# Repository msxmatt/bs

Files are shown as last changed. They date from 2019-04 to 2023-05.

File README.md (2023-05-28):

[][cc-by-sa] 

# bs
Bluetooth Sorry (BS)

# Hardware

## Specification

Please see the [specification](https://docs.google.com/document/d/1cNCA_kc3GKC5SSItixQ384-7OVhhF-bT8k4SdFTyF7Y/edit?usp=sharing) on Google Docs for more information.

# Firmware

# Licensing

## Hardware

Bluetooth Sorry (BS) hardware is licensed under a
[Creative Commons Attribution-ShareAlike 4.0 International License][cc-by-sa].  For more information, please see the LICENSE file included in this repo.

[][cc-by-sa]<br><br>
[OSHWA][open-hardware-url]

[cc-by-sa]: http://creativecommons.org/licenses/by-sa/4.0/
[cc-by-sa-image]: https://licensebuttons.net/l/by-sa/4.0/88x31.png
[cc-by-sa-shield]: https://img.shields.io/badge/License-CC%20BY--SA%204.0-lightgrey.svg
[open-hardware-url]: https://www.oshwa.org/
[open-hardware-image]: https://i0.wp.com/www.oshwa.org/wp-content/uploads/2014/03/oshw-logo-100-px.png

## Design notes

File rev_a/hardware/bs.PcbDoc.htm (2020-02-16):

Reporting Options

# File in Previous Format

Date | : | 2/16/2020
Time | : | 3:05:59 PM
Filename | : | C:\git\msx\bs\PCB\bs.PcbDoc

Version | Warning

This file was generated by an earlier version of the software

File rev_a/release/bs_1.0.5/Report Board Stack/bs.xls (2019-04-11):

Board Stack Report
Stack Up |  | Layer Stack
Layer | Board Layer Stack | Name | Material | Thickness | Constant
1 |  | Top Paste
2 |  | Top Overlay
3 |  | Top Solder | SM-001 | 1.00mil | 4
4 |  | Top Layer | Copper | 1.38mil
5 |  | Dielectric 1 | PP-021 | 7.10mil | 4.7
6 |  | Int1 (GND) | Copper | 1.38mil
7 |  | Dielectric 2 | CircuitHub-4L | 11.81mil | 4.6
8 |  | Int2 (PWR) | Copper | 1.38mil
9 |  | Dielectric 3 | PP-021 | 7.10mil | 4.7
10 |  | Bottom Layer | Copper | 1.38mil
11 |  | Bottom Solder | SM-001 | 1.00mil | 4
12 |  | Bottom Overlay
13 |  | Bottom Paste
 | Height : 33.52mil

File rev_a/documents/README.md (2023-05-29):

# Bluetooth Sorry (BS) Rev A Documents

All documentation has been converted to Google Docs and Lucidchart to make it more accessible for folks.  Please see the links below to access the documentation for this project:

### [Architecture Drawings](https://lucid.app/lucidchart/962b5e3b-6578-4df2-a3c6-de9c28ae3cac/edit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)
### [Battery Calculator](https://docs.google.com/spreadsheets/d/11GxPMdcu_zIT5CegySkwF_FRTmmZH-5FmrIwhb1siNY/edit?usp=sharing)
### [Layout Rules and Guidelines](https://docs.google.com/document/d/1B4_djOARfETP27NwB1YwL5EQ4x5ZWdFKNO-U1eI23VM/edit?usp=sharing)
### [Bring-Up Testing Overview](https://docs.google.com/spreadsheets/d/1GfkkhbxSuywVHKYCwezCMSKbZUOoyDMGrd5bFZc0WWg/edit?usp=sharing)
### [Rev B Fixes and Ideas](https://docs.google.com/document/d/1f-UJx_TAneLSBL5eTnIvvRchRN2FdRKdbjY0LI8uTsM/edit?usp=drive_link)

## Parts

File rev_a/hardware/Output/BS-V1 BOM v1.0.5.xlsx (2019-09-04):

BOM: |  |  | BS-V1
Assembly Part Number: |  |  | BS-V1-ASSY
Revision: |  |  | 1.0.5
Customer / Company Name: |  |  | MSX Consulting, LLC
Item # | Quantity | Manufacturer | Manufacturer Part Number | Level | Fitted | Designator | Supplier 1 | Supplier Part Number 1 | Comment | Footprint | Description
1 | 3 | Samsung | CL05A106MP5NUNC | 1 | Fitted | C1, C10, C12 | Digi-Key | 1276-1450-1-ND | 10uF | C0402 | CAP CER 10UF 10V X5R 0402
2 | 3 | Samsung | CL05A475MO5NUNC | 1 | Fitted | C2, C3, C9 | Digi-Key | 1276-6836-1-ND | 4.7uF | C0402 | CAP CER 4.7UF 16V X5R 0402
3 | 2 | Taiyo Yuden | TMK105BJ105MV-F | 1 | Fitted | C4, C6 | Digi-Key | 587-3245-1-ND | 1uF | C0402 | CAP CER 1UF 25V X5R 0402
4 | 4 | Murata | GRM033R61C104ME84D | 1 | Fitted | C5, C7, C8, C14 | Digi-Key | 490-9986-1-ND | 0.1uF | C0201 | CAP CER 0.1UF 16V X5R 0201
5 | 1 | Murata | GRM155R71E103KA01D | 1 | Fitted | C11 | Digi-Key | 490-1312-1-ND | 10000pF | C0402 | CAP CER 10000PF 25V X7R 0402
6 | 1 | Murata | GRM155R71C153KA01J | 1 | Fitted | C13 | Digi-Key | 490-6329-1-ND | 0.015uF | C0402 | CAP CER 0.015UF 16V X7R 0402
7 | 2 | STMicroelectronics | ESDAXLC6-1BU2 | 1 | Fitted | D1, D7 | Digi-Key | 497-13414-1-ND | ESDAXLC6-1BU2 | ONS_0201 | TVS DIODE 3V 17V ST0201
8 | 2 | Dialight | 598-8070-107F | 1 | Fitted | D2, D6 | Digi-Key | 350-2035-1-ND | 5988070107F | LED0603 | LED GREEN CLEAR 0603 SMD
9 | 1 | MCC | 1N4148X-TP | 1 | Fitted | D3 | Digi-Key | 1N4148XTPMSCT-ND | 1N4148X-TP | MCC_SOD523 | DIODE GEN PURP 75V 150MA SOD523
10 | 1 | NXP Semiconductors | PMEG2020EPK,315 | 1 | Fitted | D4 | Digi-Key | 1727-1338-1-ND | PMEG2020EPK | NXP_DFN1608D-2 | DIODE SCHOTTKY 20V 2A 2DFN
11 | 1 | Dialight | 598-8091-107F | 1 | Fitted | D5 | Digi-Key | 350-2037-1-ND | 5988091107F | LED0603 | LED BLUE CLEAR 0603 SMD
12 | 1 | STMicroelectronics | ESDA7P60-1U1M | 1 | Fitted | D8 | Digi-Key | 497-16253-1-ND | ESDA7P60-1U1M | STM_1610 | TVS DIODE 5V 11.6V 1610
13 | 1 | Amphenol FCI | 10132328-10011LF | 1 | Fitted | J1 | Digi-Key | 609-5380-1-ND | 10132328-10011LF | AMP_USBC_VT | CONN RCPT USB3.1 TYPEC 24POS SMD
14 | 1 | Tag Connect | TC2030-IDC-NL | 1 | Fitted | J2 | N/A | N/A | TC2030-IDC-NL | TAG_6P | TAG CONNECT 6PIN SWD
15 | 1 | JST | B2B-ZR(LF)(SN) | 1 | Fitted | J3 | Digi-Key | 455-1657-ND | B2B-ZR(LF)(SN) | JST_ZH_2P_PTH_VT | CONN HEADER ZH TOP 2POS 1.5MM
16 | 1 | Sullins | GRPB022VWVN-RC | 1 | Fitted | J4 | Digi-Key | S9015E-02-ND | GRPB022VWVN-RC | HDR10_2X2_0.05IN | CONN HEADER VERT 4POS 1.27MM
17 | 1 | Murata | BLM15PX601SN1D | 1 | Fitted | L1 | Digi-Key | 490-9657-1-ND | BLM15PX601SN1D | L0402 | FERRITE BEAD 600 OHM 0402 1LN
18 | 1 | Diodes | DMP21D0UFB4-7B | 1 | Fitted | Q1 | Digi-Key | DMP21D0UFB4-7BDICT-ND | DMP21D0UFB4-7B | DIO_X2-DFN1006-3 | MOSFET P-CH 20V 770MA 3DFN
19 | 2 | Yageo | RC0402FR-075K1L | 1 | Fitted | R1, R2 | Digi-Key | 311-5.10KLRCT-ND | 5.1k | R0402 | RES SMD 5.1K OHM 1% 1/16W 0402
20 | 2 | Yageo | RC0402FR-0747RL | 1 | Fitted | R3, R15 | Digi-Key | 311-47.0LRCT-ND | 47R | R0402 | RES SMD 47 OHM 1% 1/16W 0402
21 | 2 | Yageo Phycomp | RC0402FR-0710KL | 1 | Fitted | R4, R11 | Digi-Key | 311-10.0KLRCT-ND | 10k | R0402 | RES SMD 10K OHM 1% 1/16W 0402
22 | 3 | Yageo | RC0402FR-071KL | 1 | Fitted | R5, R9, R16 | Digi-Key | 311-1.00KLRCT-ND | 1k | R0402 | RES SMD 1K OHM 1% 1/16W 0402
23 | 1 | Yageo | RC0402FR-072KL | 1 | Fitted | R6 | Digi-Key | 311-2KLRCT-ND | 2k | R0402 | RES SMD 2K OHM 1% 1/16W 0402
24 | 1 | Panasonic | ERJ-2RKF8063X | 1 | Fitted | R7 | Digi-Key | P806KLCT-ND | 806k | R0402 | RES SMD 806K OHM 1% 1/10W 0402
25 | 1 | Samsung | RC1005F205CS | 1 | Fitted | R8 | Digi-Key | 1276-4293-1-ND | 2M | R0402 | RES SMD 2M OHM 1% 1/16W 0402
26 | 1 | Yageo | RC0402FR-070RL | 1 | Fitted | R12 | Digi-Key | 311-0.0LRCT-ND | 0R | R0402 | RES SMD 0 OHM JUMPER 1/16W 0402
27 | 1 | Yageo | RC0402FR-07100KL | 1 | Fitted | R13 | Digi-Key | 311-100KLRCT-ND | 100k | R0402 | RES SMD 100K OHM 1% 1/16W 0402
28 | 1 | Panasonic | ERJ-2RKF3571X | 1 | Fitted | R14 | Digi-Key | P3.57KLCT-ND | 3.57k | R0402 | RES SMD 3.57K OHM 1% 1/10W 0402
29 | 1 | Panasonic | ERJ-2RKF1151X | 1 | Fitted | R17 | Digi-Key | P1.15KLCT-ND | 1.15k | R0402 | RES SMD 1.15K OHM 1% 1/10W 0402
30 | 1 | TE Connectivity Alcoswitch | FSMIJM61AB04 | 1 | Fitted | SW1 | Digikey | 450-2207-1-ND | FSMIJM61AB04 | TE_FSMIJM61AB04 | SWITCH TACTILE SPST-NO 50MA 12V
31 | 1 | Panasonic | EXC-14CS350H | 1 | Fitted | U1 | Digi-Key | P19421CT-ND | EXC-14CS350H | PAN_EXC14CS | CMC 100MA 2LN 35 OHM SMD ESD
32 | 1 | Seeed Studio | 317030213 | 1 | Fitted | U2 | Digi-Key | 1597-1434-ND | MDBT42Q | RAY_MDBT42Q | MDBT42Q NRF52832 BASED BLE MODUL
33 | 1 | Microchip | MCP73831T-2ATI/OT | 1 | Fitted | U3 | Digi-Key | MCP73831T-2ATI/OTCT-ND | MCP73831T-2ATI/OT | MCP_SOT23-5 | IC CONTROLLR LI-ION 4.2V SOT23-5
34 | 1 | Silicon Labs | CP2104-F03-GMR | 1 | Fitted | U4 | Digi-Key | 336-4146-1-ND | CP2104-F03-GMR | SIL_QFN-24 | IC SGL USB-TO-UART BRIDGE 24QFN
35 | 1 | Texas Instruments | TPS7A9001DSKR | 1 | Fitted | U5 | Digi-Key | 296-48316-1-ND | TPS7A9001DSKR | TI_DSK | ULTRA LOW NOISE 0.5A LDO WITH P
END OF BOM

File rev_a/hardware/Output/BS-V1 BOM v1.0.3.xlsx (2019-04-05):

BOM: BS-V1
Assembly Part Number/Revision: BS-V1-ASSY v1.0.3
Customer / Company Name: MSX Consulting, LLC.
Item # | Qty | Manfacturer | Manufacturer Part # | Level | Do Not Install | Reference designators | Vendor | Vendor Part Number | Value | Size / Footprint | Description
1 | 3 | Samsung | CL05A106MP5NUNC | 1 |  | C1, C10, C12 | Digi-Key | 1276-1450-1-ND | 10uF | C0402 | CAP CER 10UF 10V X5R 0402
2 | 3 | Samsung | CL05A475MO5NUNC | 1 |  | C2, C3, C9 | Digi-Key | 1276-6836-1-ND | 4.7uF | C0402 | CAP CER 4.7UF 16V X5R 0402
3 | 2 | Taiyo Yuden | TMK105BJ105MV-F | 1 |  | C4, C6 | Digi-Key | 587-3245-1-ND | 1uF | C0402 | CAP CER 1UF 25V X5R 0402
4 | 3 | Taiyo Yuden | TMK105B7104KVHF | 1 |  | C5, C7, C8 | Digi-Key | 587-3773-1-ND | 0.1uF | C0402 | CAP CER 0.1UF 25V X7R 0402
5 | 1 | Murata | GRM155R71E103KA01D | 1 |  | C11 | Digi-Key | 490-1312-1-ND | 10000pF | C0402 | CAP CER 10000PF 25V X7R 0402
6 | 1 | Murata | GRM155R71C153KA01J | 1 |  | C13 | Digi-Key | 490-6329-1-ND | 0.015uF | C0402 | CAP CER 0.015UF 16V X7R 0402
7 | 1 | STMicroelectronics | ESDAXLC6-1BU2 | 1 |  | D1 | Digi-Key | 497-13414-1-ND | ESDAXLC6-1BU2 | ONS_0201 | TVS DIODE 3V 17V ST0201
8 | 2 | Dialight | 598-8070-107F | 1 |  | D2, D6 | Digi-Key | 350-2035-1-ND | 5988070107F | LED0603 | LED GREEN CLEAR 0603 SMD
9 | 1 | ON Semiconductor | MMBD914LT1G | 1 |  | D3 | Digi-Key | MMBD914LT1GOSCT-ND | MMBD914LT1G | ONS_SOT23 | DIODE GEN PURP 100V 200MA SOT23
10 | 1 | NXP Semiconductors | PMEG2020EPK,315 | 1 |  | D4 | Digi-Key | 1727-1338-1-ND | PMEG2020EPK | NXP_DFN1608D-2 | DIODE SCHOTTKY 20V 2A 2DFN
11 | 1 | Dialight | 598-8091-107F | 1 |  | D5 | Digi-Key | 350-2037-1-ND | 5988091107F | LED0603 | LED BLUE CLEAR 0603 SMD
12 | 1 | Amphenol FCI | 10132328-10011LF | 1 |  | J1 | Digi-Key | 609-5380-1-ND | 10132328-10011LF | AMP_USBC_VT | CONN RCPT USB3.1 TYPEC 24POS SMD
13 | 1 | Tag-Connect | TC2030-IDC-NL | 1 | DNI | J2 | N/A | N/A | TC2030-IDC-NL | TAG_6P | TAG CONNECT 6PIN SWD
14 | 1 | JST | B2B-ZR(LF)(SN) | 1 |  | J3 | Digi-Key | 455-1657-ND | B2B-ZR(LF)(SN) | JST_ZH_2P_PTH_VT | CONN HEADER ZH TOP 2POS 1.5MM
15 | 1 | Harwin | M22-5320546 | 1 |  | J4 | Digi-Key | 952-3345-ND | M22-5320546 | HDR10_2X5_2MM | CONN HEADER SMD 10POS 2MM
16 | 1 | Diodes | DMP21D0UFB4-7B | 1 |  | Q1 | Digi-Key | DMP21D0UFB4-7BDICT-ND | DMP21D0UFB4-7B | DIO_X2-DFN1006-3 | MOSFET P-CH 20V 770MA 3DFN
17 | 2 | Yageo | RC0402FR-075K1L | 1 |  | R1, R2 | Digi-Key | 311-5.10KLRCT-ND | 5.1k | R0402 | RES SMD 5.1K OHM 1% 1/16W 0402
18 | 2 | Yageo | RC0402FR-0747RL | 1 |  | R3, R15 | Digi-Key | 311-47.0LRCT-ND | 47R | R0402 | RES SMD 47 OHM 1% 1/16W 0402
19 | 2 | Yageo | RC0402FR-0710KL | 1 |  | R4, R11 | Digi-Key | 311-10.0KLRCT-ND | 10k | R0402 | RES SMD 10K OHM 1% 1/16W 0402
20 | 3 | Yageo | RC0402FR-071KL | 1 |  | R5, R9, R16 | Digi-Key | 311-1.00KLRCT-ND | 1k | R0402 | RES SMD 1K OHM 1% 1/16W 0402
21 | 1 | Yageo | RC0402FR-072KL | 1 |  | R6 | Digi-Key | 311-2KLRCT-ND | 2k | R0402 | RES SMD 2K OHM 1% 1/16W 0402
22 | 1 | Panasonic | ERJ-2RKF8063X | 1 |  | R7 | Digi-Key | P806KLCT-ND | 806k | R0402 | RES SMD 806K OHM 1% 1/10W 0402
23 | 1 | Samsung | RC1005F205CS | 1 |  | R8 | Digi-Key | 1276-4293-1-ND | 2M | R0402 | RES SMD 2M OHM 1% 1/16W 0402
24 | 1 | Yageo | RC0402FR-074K7L | 1 |  | R10 | Digi-Key | 311-4.7KLRCT-ND | 4.7k | R0402 | RES SMD 4.7K OHM 1% 1/16W 0402
25 | 1 | Yageo | RC0402FR-070RL | 1 |  | R12 | Digi-Key | 311-0.0LRCT-ND | 0R | R0402 | RES SMD 0 OHM JUMPER 1/16W 0402
26 | 1 | Yageo | RC0402FR-07100KL | 1 |  | R13 | Digi-Key | 311-100KLRCT-ND | 100k | R0402 | RES SMD 100K OHM 1% 1/16W 0402
27 | 1 | Panasonic | ERJ-2RKF3571X | 1 |  | R14 | Digi-Key | P3.57KLCT-ND | 3.57k | R0402 | RES SMD 3.57K OHM 1% 1/10W 0402
28 | 1 | Panasonic | ERJ-2RKF1151X | 1 |  | R17 | Digi-Key | P1.15KLCT-ND | 1.15k | R0402 | RES SMD 1.15K OHM 1% 1/10W 0402
29 | 1 | TE Connectivity Alcoswitch | FSMIJM61AB04 | 1 |  | SW1 | Digi-Key | 450-2207-1-ND | FSMIJM61AB04 | TE_FSMIJM61AB04 | SWITCH TACTILE SPST-NO 50MA 12V
30 | 1 | ITT C&K | PTS645SM43SMTR92LFS | 1 |  | SW2 | Digi-Key | CKN9112CT-ND | PTS645SM43SMTR92LFS | CK_PTS645 | SWITCH TACTILE SPST-NO 0.05A 12V
31 | 1 | STMicroelectronics | ECMF02-4CMX8 | 1 |  | U1 | Digi-Key | 497-13420-1-ND | ECMF02-4CMX8 | STM_UQFN-8L | COMMON MODE CHOKE 2LN SMD ESD
32 | 1 | Seeed Studio | 317030213 | 1 |  | U2 | Digi-Key | 1597-1434-ND | MDBT42Q | RAY_MDBT42Q | MDBT42Q NRF52832 BASED BLE MODUL
33 | 1 | Microchip | MCP73831T-2ATI/OT | 1 |  | U3 | Digi-Key | MCP73831T-2ATI/OTCT-ND | MCP73831T-2ATI/OT | MCP_SOT23-5 | IC CONTROLLR LI-ION 4.2V SOT23-5
34 | 1 | Silicon Labs | CP2104-F03-GMR | 1 |  | U4 | Digi-Key | 336-4146-1-ND | CP2104-F03-GMR | SIL_QFN-24 | IC SGL USB-TO-UART BRIDGE 24QFN
35 | 1 | Texas Instruments | TPS7A9001DSKR | 1 |  | U5 | Digi-Key | 296-48316-1-ND | TPS7A9001DSKR | TI_DSK | ULTRA LOW NOISE 0.5A LDO WITH P
END OF BOM

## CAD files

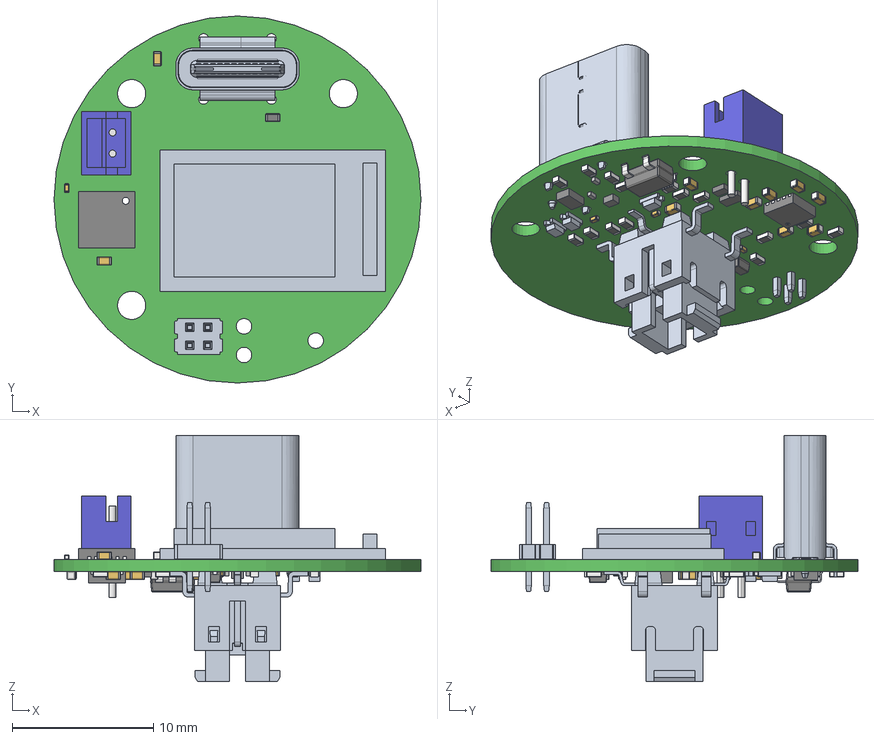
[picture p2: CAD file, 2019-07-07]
rev_a/mechanical/MCO Mockup v1.1.step
26.0 x 26.0 x 17.5 mm
Open_CASCADE_STEP_translator_6.8_1.1.1 x 7
Open_CASCADE_STEP_translator_6.8_1.1.2 x 5
Open_CASCADE_STEP_translator_6.8_1.2.1 x 38
bigPin x 5
Open_CASCADE_STEP_translator_6.8_5.1.1 x 10
Open_CASCADE_STEP_translator_6.8_5.1.2 x 10
Open_CASCADE_STEP_translator_6.8_5.2.1 x 10
Extruded x 3
c-2213819-1-a-3d
Open_CASCADE_STEP_translator_6.8_2.1
Open_CASCADE_STEP_translator_6.8_2.2.1
Thermal_Shape x 2
Open_CASCADE_STEP_translator_6.8_2.4.1 x 10
Open_CASCADE_STEP_translator_6.8_2.4.2 x 10
Open_CASCADE_STEP_translator_6.8_1.1
Open_CASCADE_STEP_translator_6.8_1.4.1 x 24
Leader x 5
mdbt42q
Mid_Body x 16
Mark x 16
smallPine x 2
_____B022VWVN-RC
B2B-ZR
10132328-10011LF
0603_single x 3
lead x 2

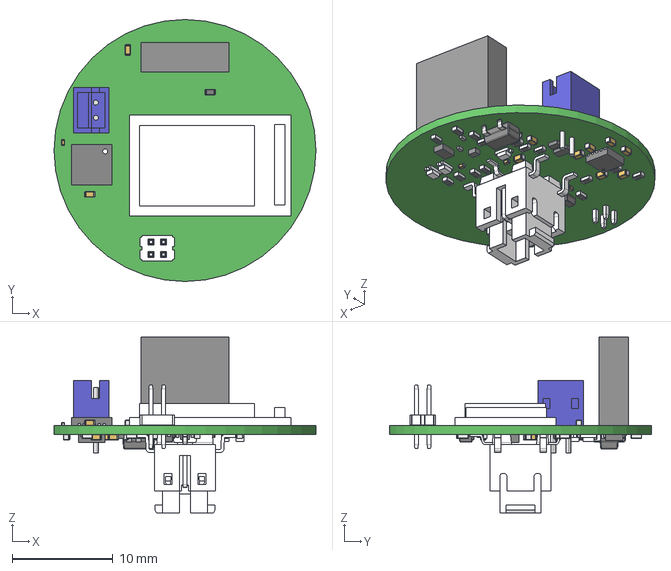
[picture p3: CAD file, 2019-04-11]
rev_a/release/bs_1.0.5/ExportSTEP/bs.step
26.0 x 26.0 x 17.5 mm

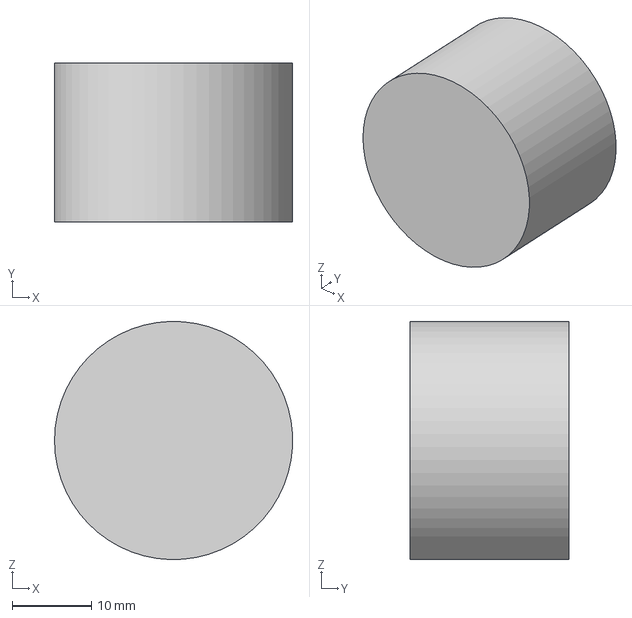
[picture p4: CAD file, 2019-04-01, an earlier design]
rev_a/mechanical/MCO Mockup v1.step
30.0 x 20.0 x 30.0 mm

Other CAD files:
rev_a/mechanical/MCO.dwg

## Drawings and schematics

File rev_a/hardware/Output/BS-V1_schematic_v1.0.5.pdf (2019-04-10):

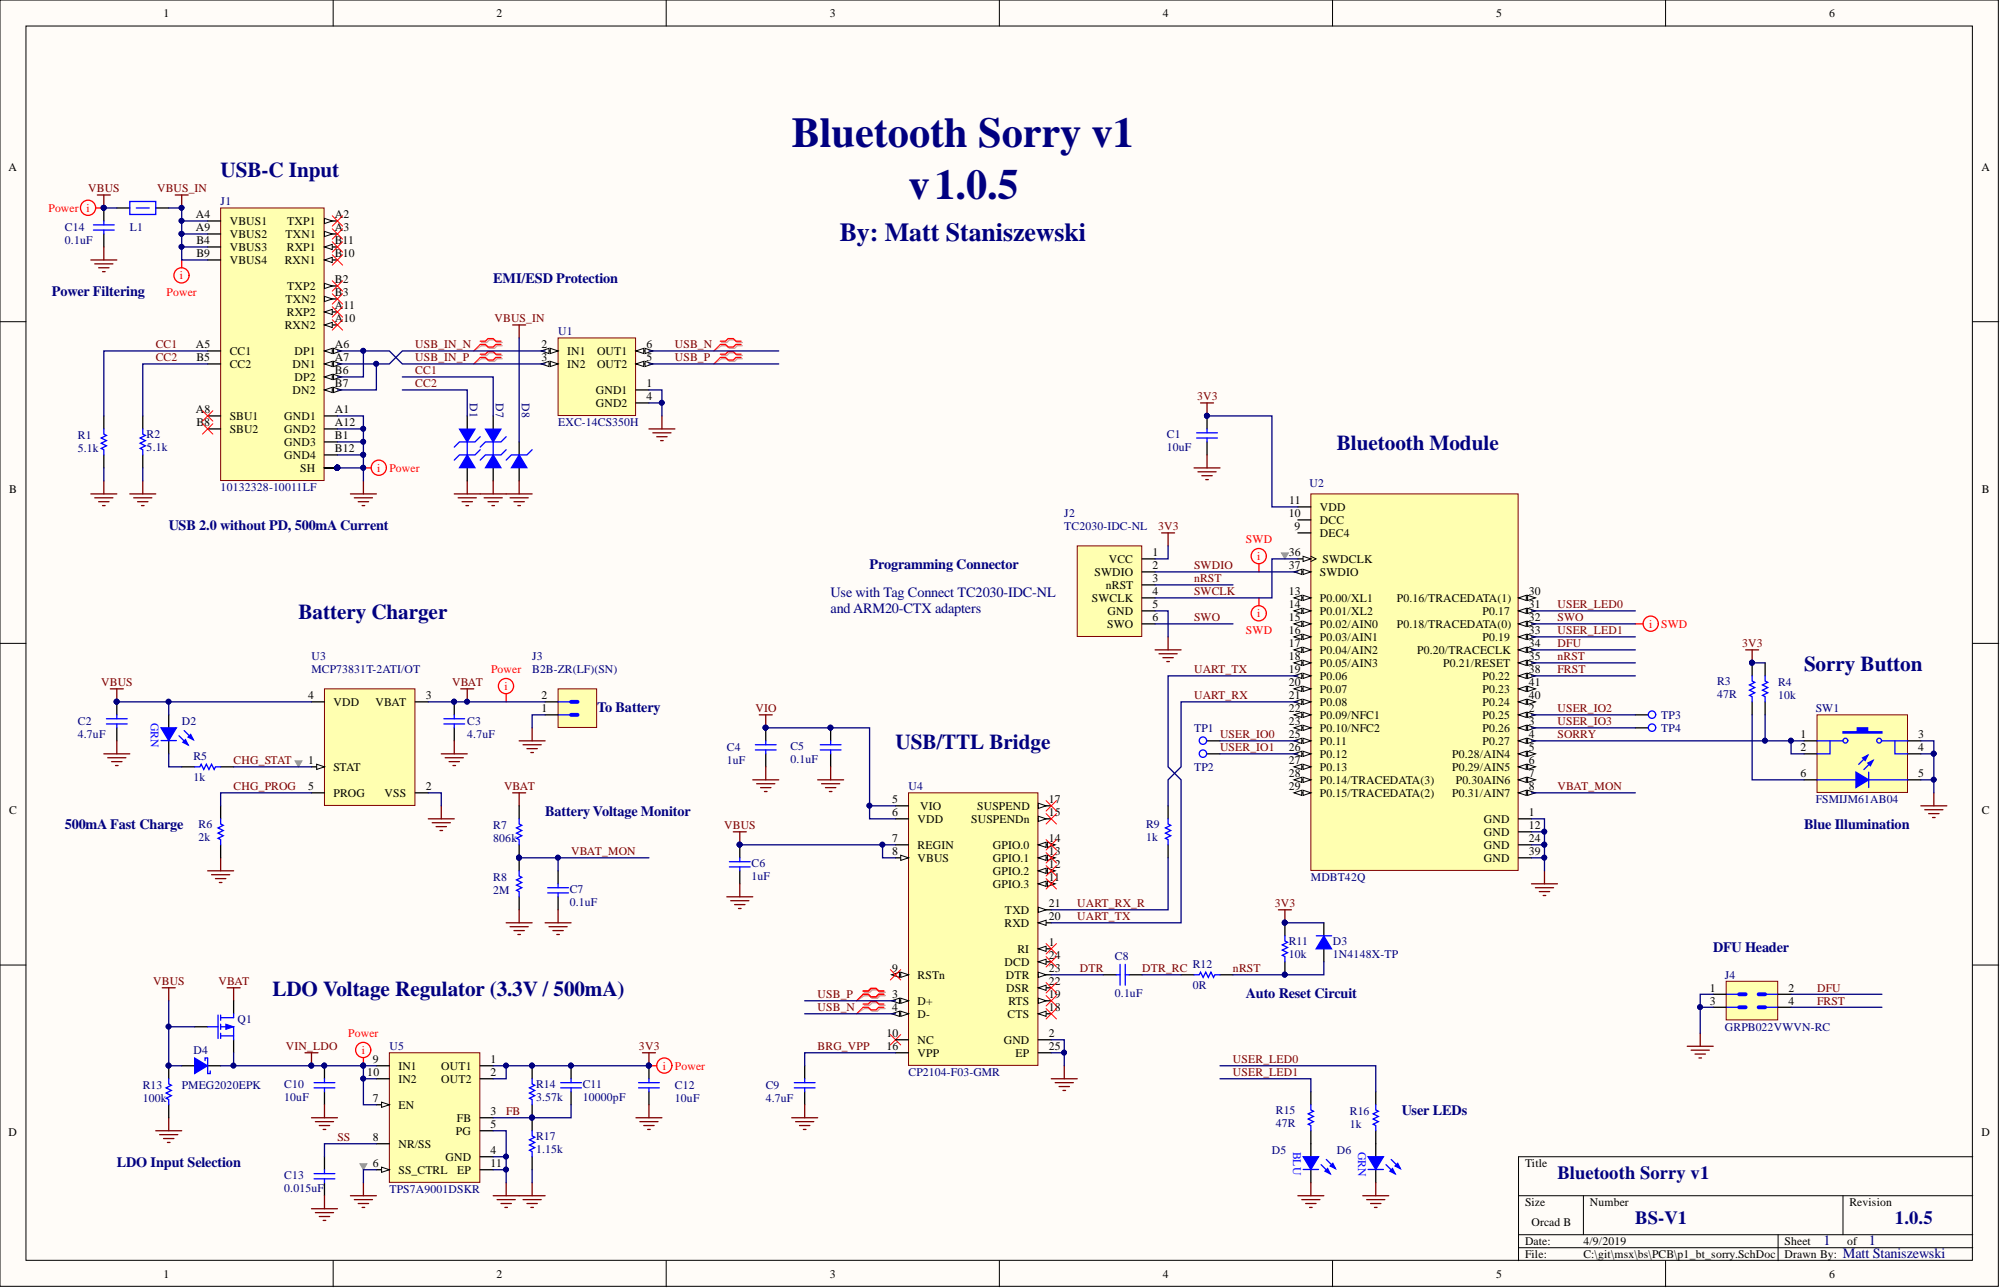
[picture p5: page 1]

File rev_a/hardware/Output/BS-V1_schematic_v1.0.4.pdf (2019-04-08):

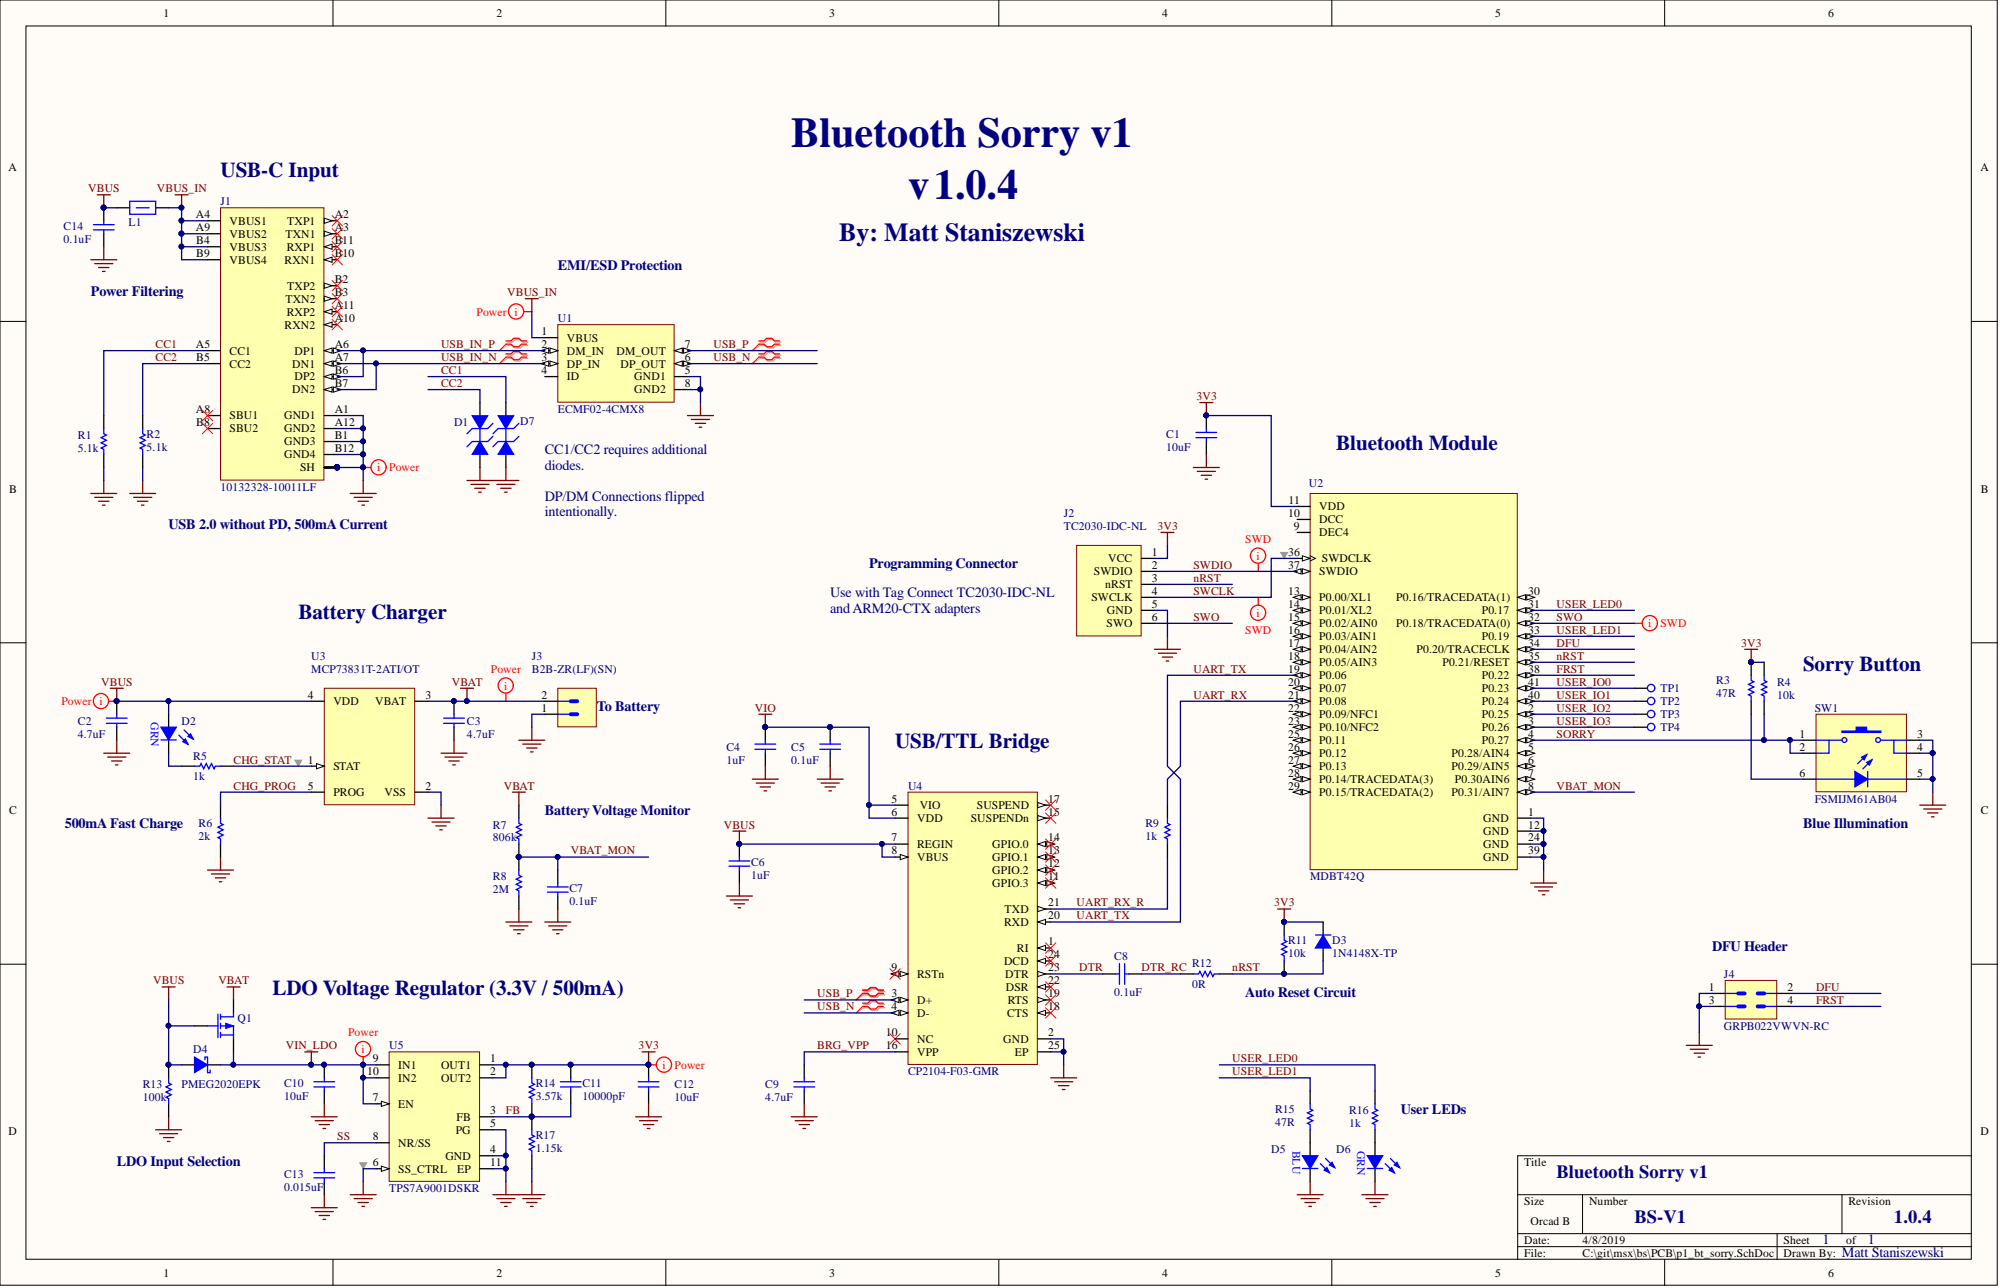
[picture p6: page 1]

CC2 | | CC2 B5 | A 7 | USB_IN _ N 3

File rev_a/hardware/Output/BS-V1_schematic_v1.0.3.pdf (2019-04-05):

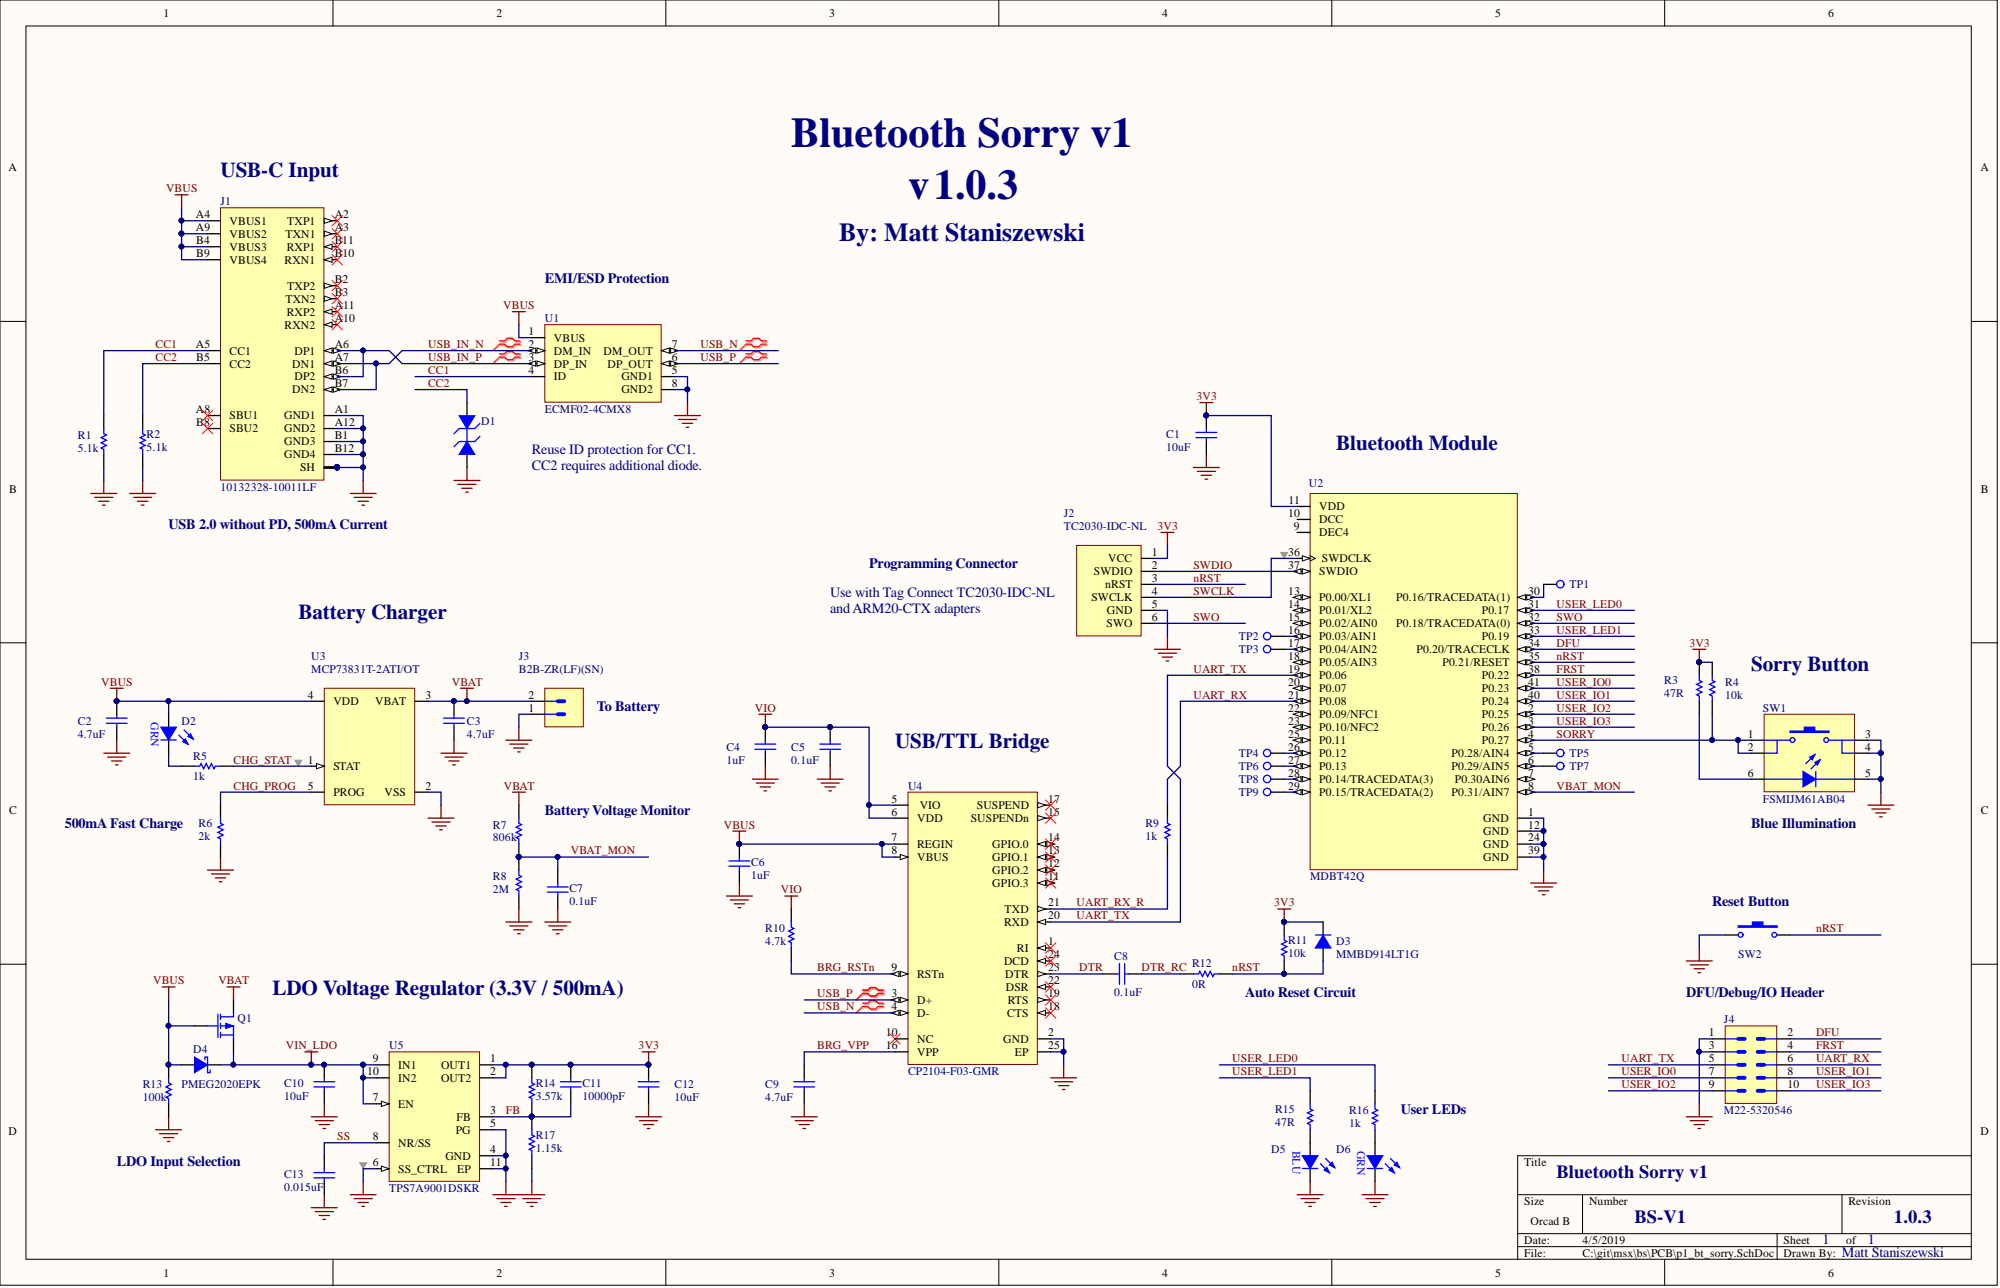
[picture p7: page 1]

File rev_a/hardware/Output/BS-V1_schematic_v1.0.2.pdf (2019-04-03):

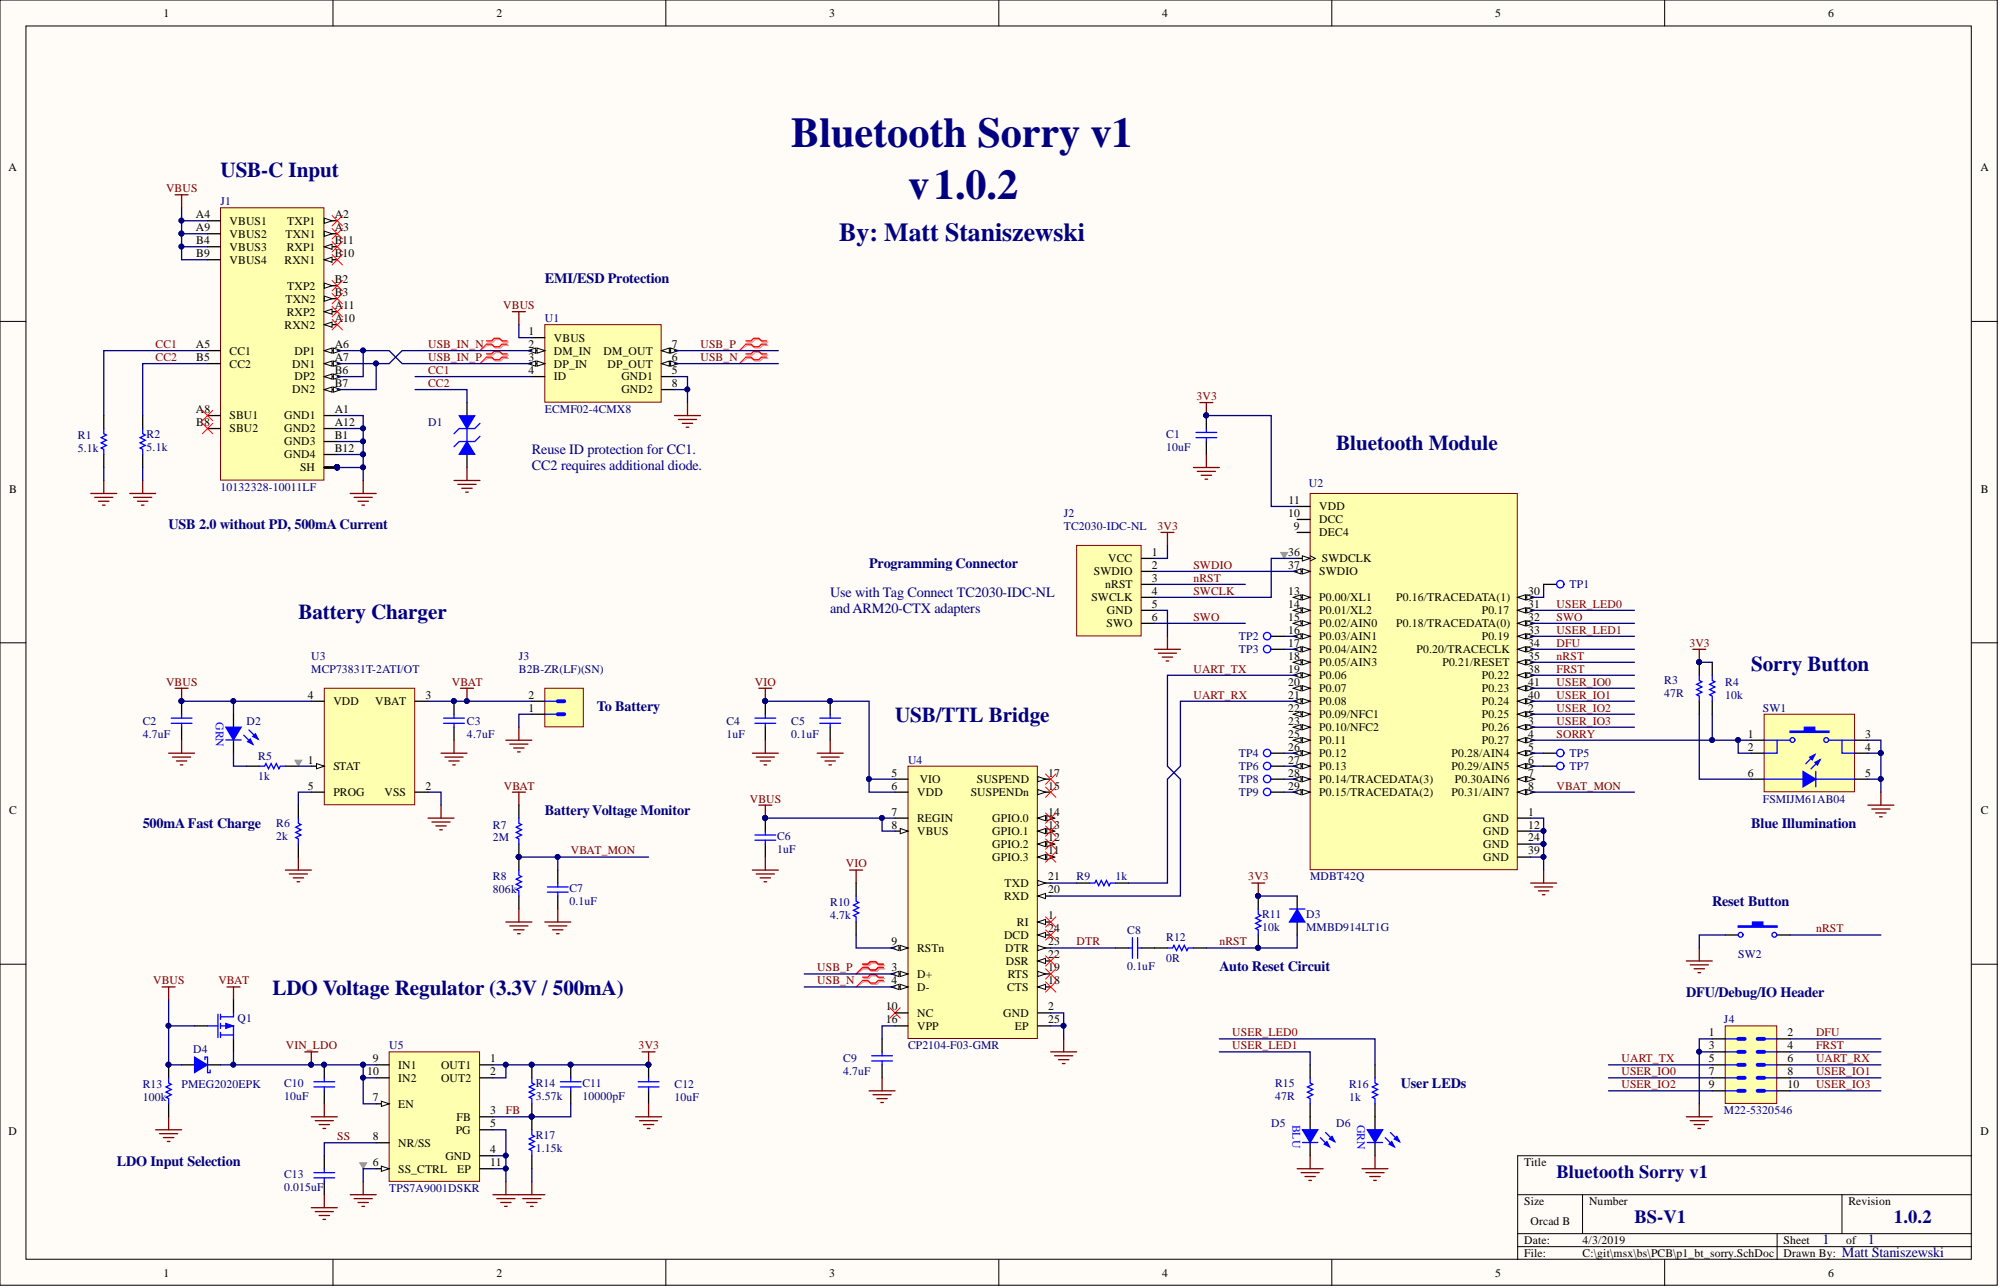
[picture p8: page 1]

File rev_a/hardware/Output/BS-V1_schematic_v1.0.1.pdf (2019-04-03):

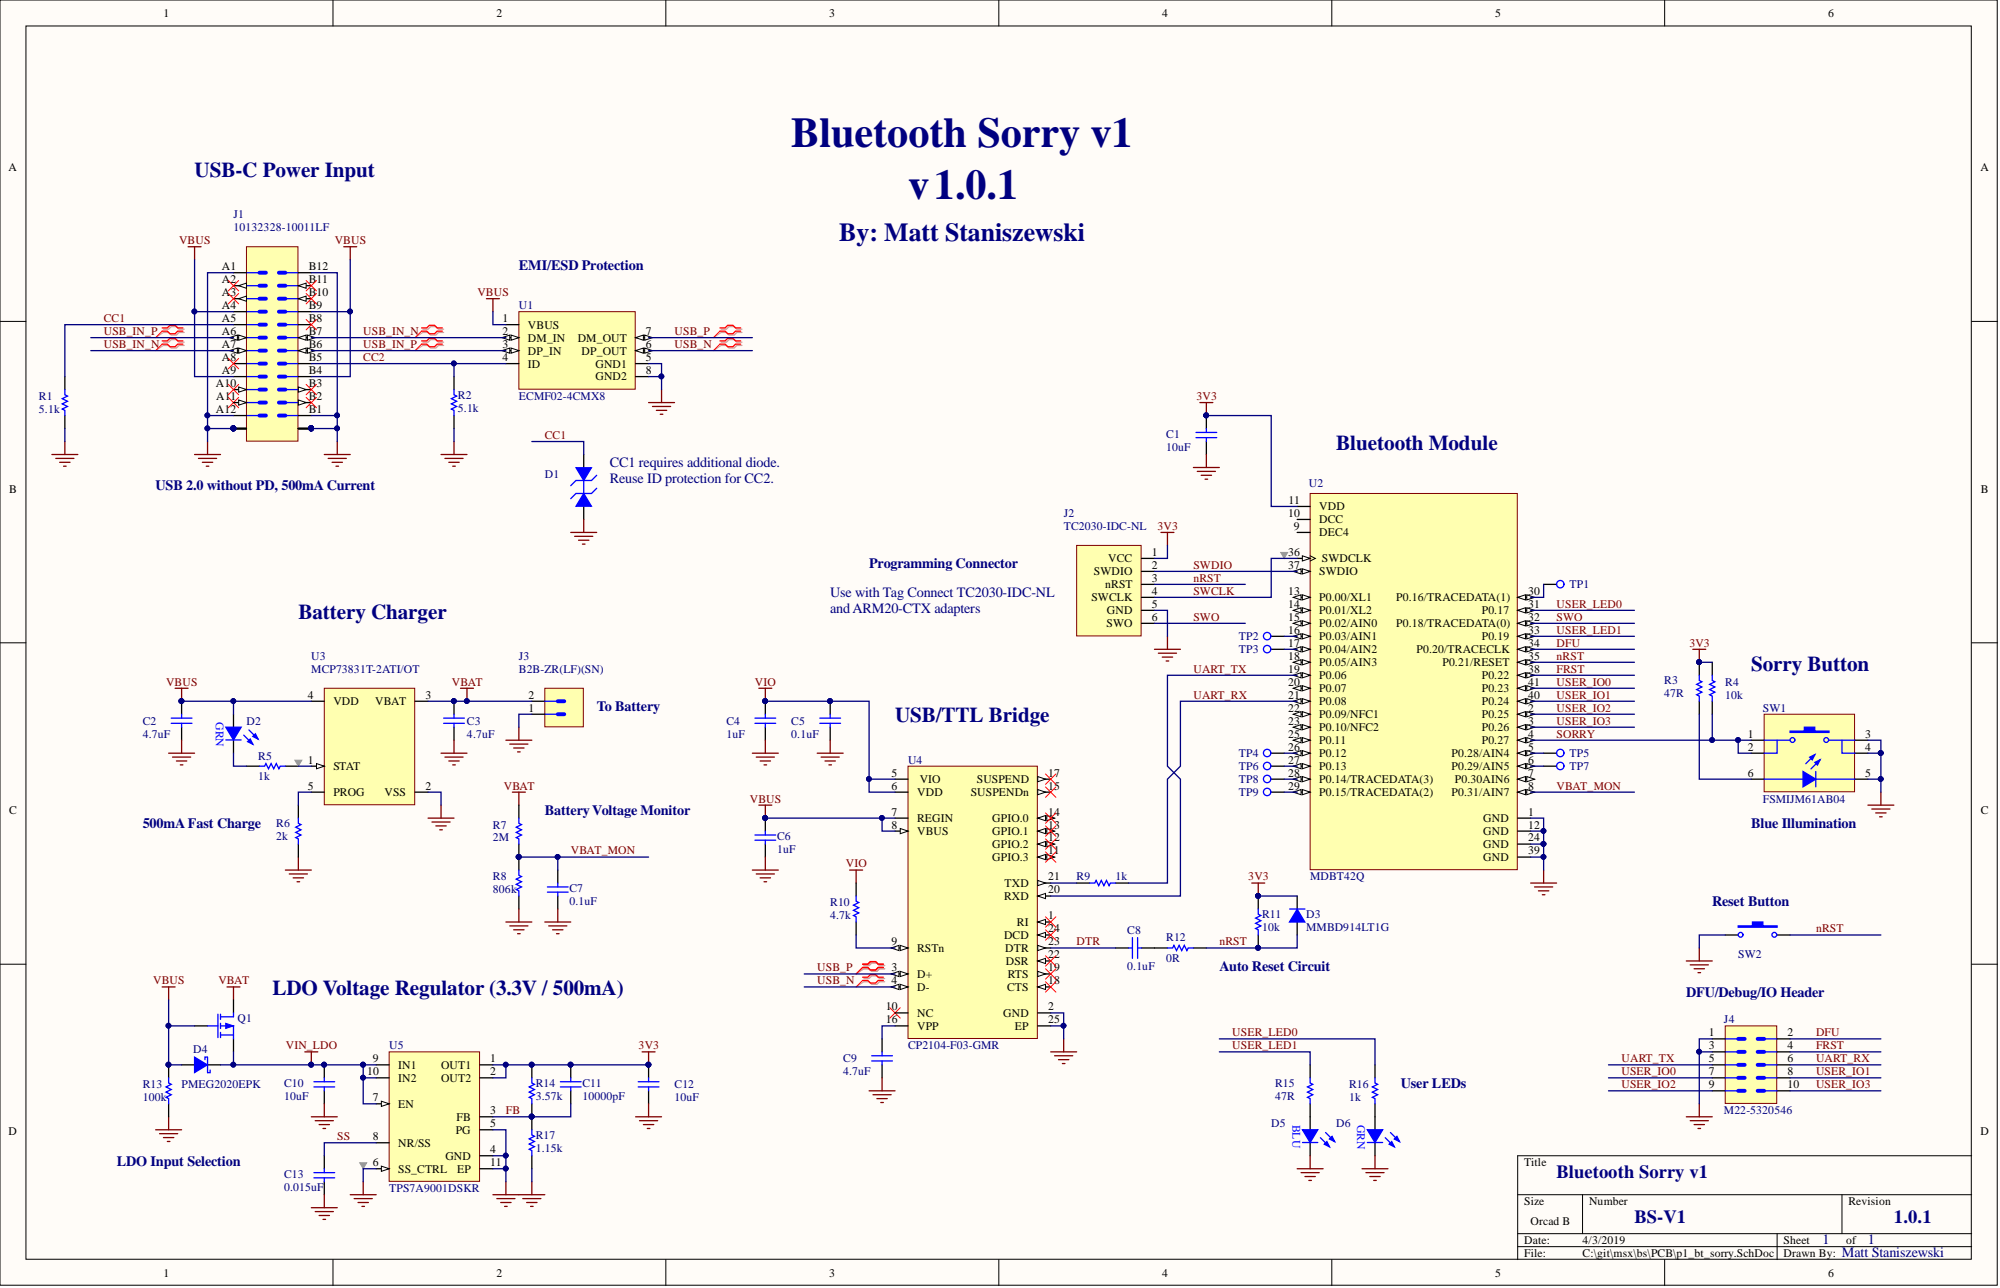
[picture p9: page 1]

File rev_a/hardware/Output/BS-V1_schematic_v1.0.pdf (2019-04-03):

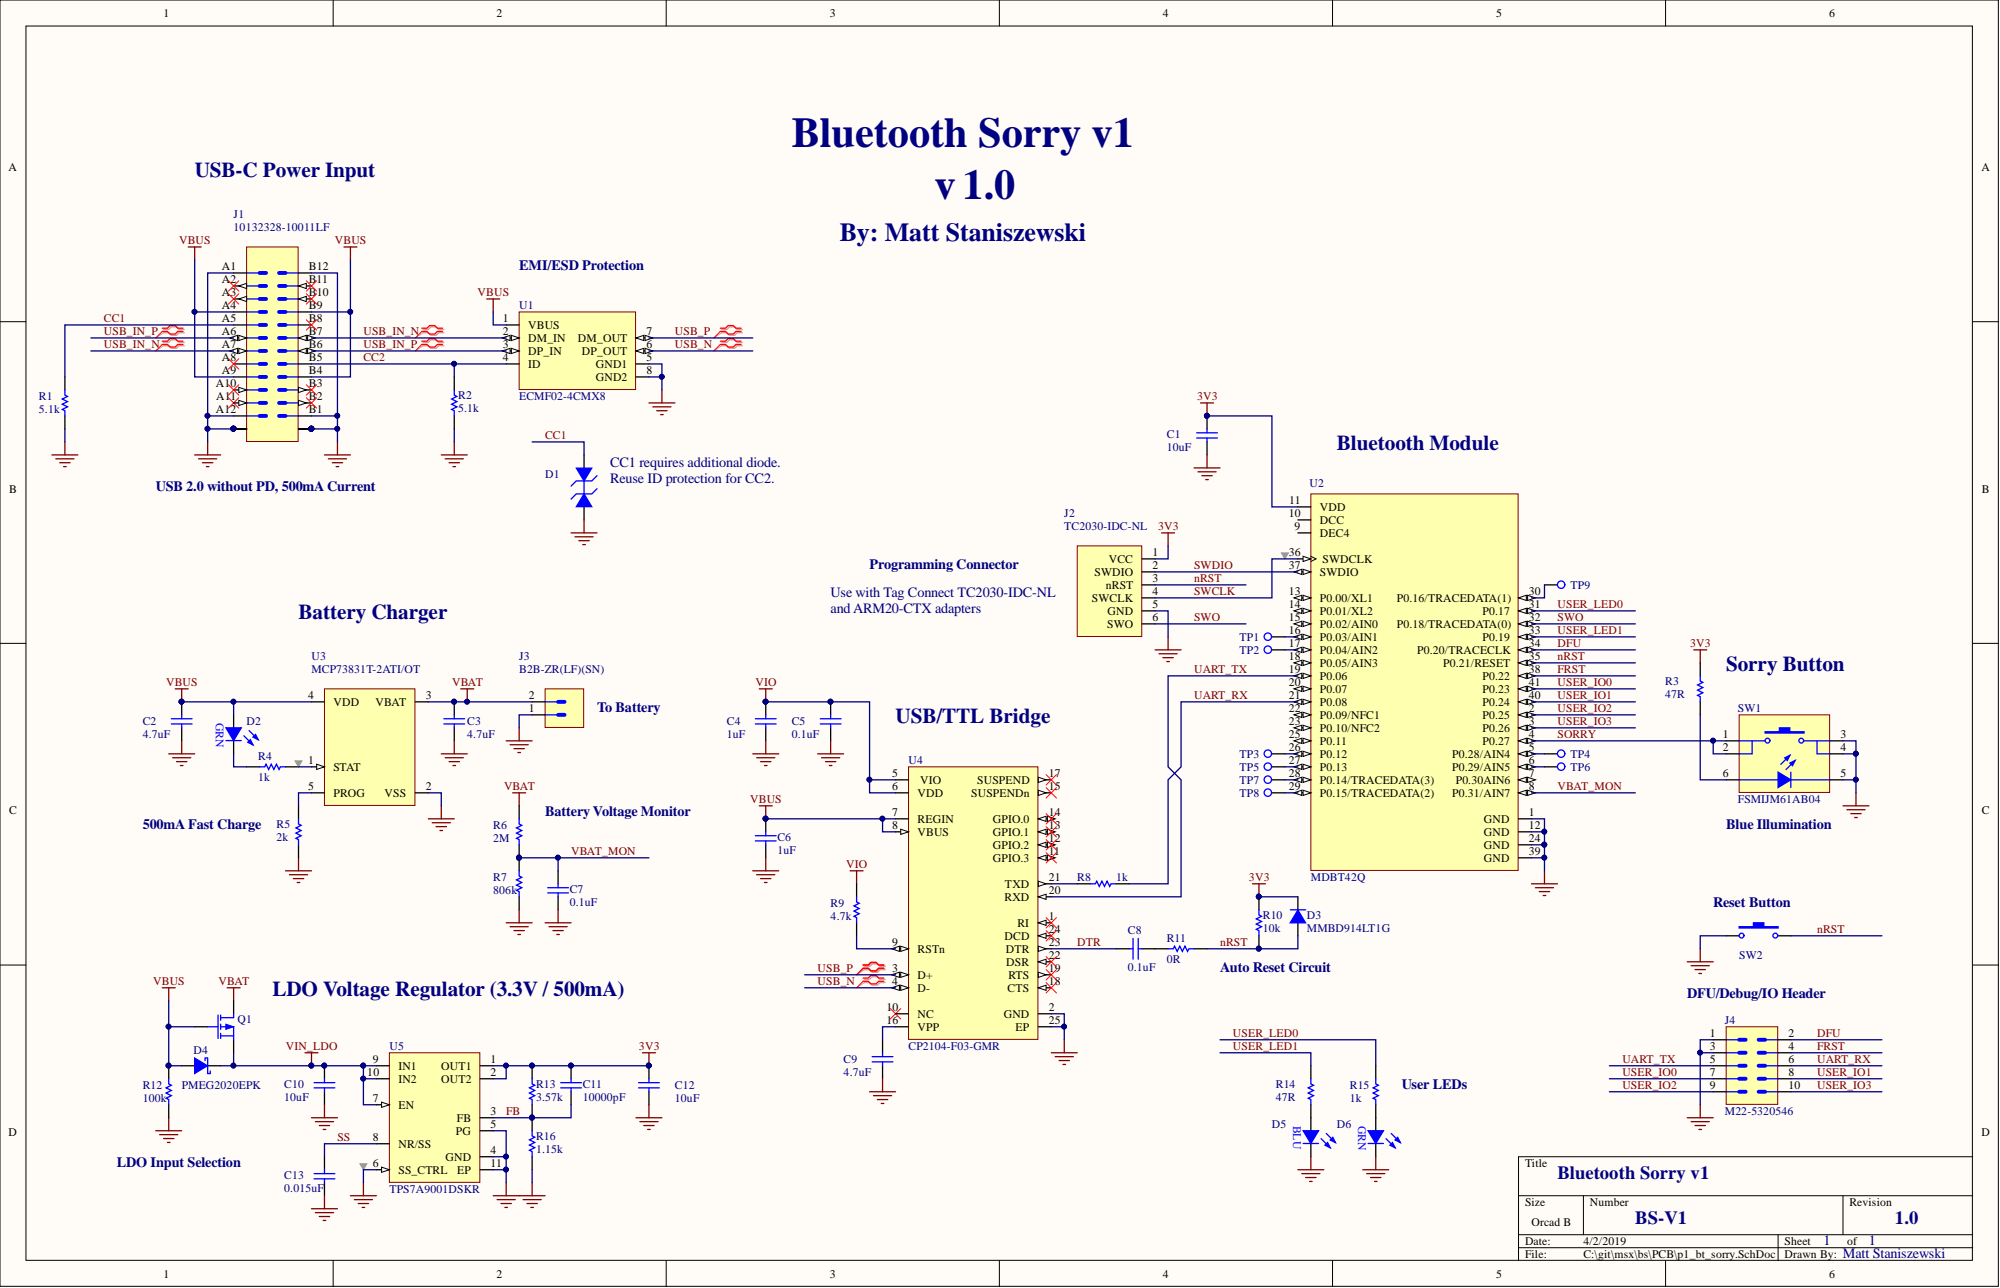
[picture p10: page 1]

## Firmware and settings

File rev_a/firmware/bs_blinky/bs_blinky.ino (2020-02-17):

int bs_green_led = 17;
int bs_blue_led = 19;

// the setup function runs once when you press reset or power the board
void setup() {
  // initialize digital pins for LEDs as outputs.
  pinMode(bs_green_led, OUTPUT);
  pinMode(bs_blue_led, OUTPUT);

  // turn off both LEDs to start
  digitalWrite(bs_green_led, LOW);
  digitalWrite(bs_blue_led, LOW);
}

     
// the loop function runs over and over again forever
void loop() {

  // blink blue LED every 500ms, green LED every 1s
  digitalWrite(bs_green_led, HIGH);
  digitalWrite(bs_blue_led, HIGH);
  delay(500);
  digitalWrite(bs_blue_led, LOW);
  delay(500);
  digitalWrite(bs_green_led, LOW);
  digitalWrite(bs_blue_led, HIGH);
  delay(500);
  digitalWrite(bs_blue_led, LOW);
  delay(500);
  
}

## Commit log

2019-04-01 Add battery calculations, clean up drawings
    [Battery Calculator.xlsx]
2019-04-01 Updated battery connector, added ME mockup
    [MCO Mockup v1.step]
2019-04-02 Added schematic, ignore file
    [bs.PrjPcb, p1_bt_sorry.SchDoc]
2019-04-03 Working on it...
    [bs.PrjPcb, p1_bt_sorry.SchDoc]
2019-04-03 Schematic draft almost done
    [p1_bt_sorry.SchDoc]
2019-04-03 Prep for initial scrub
    [p1_bt_sorry.SchDoc]
2019-04-03 BS Schematic (v1.0): Initial Version
    [bs.PrjPcb, p1_bt_sorry.SchDoc]
2019-04-03 BS Schematic (v1.0.1): Added Sorry Pull-Up
    [bs.PrjPcb, p1_bt_sorry.SchDoc]
2019-04-03 BS Schematic (v1.0.2): More Readable USB-C Symbol
    [bs.PrjPcb, p1_bt_sorry.SchDoc]
2019-04-05 BS Schematic (v1.0.3): Reviews Completed, BOM Generated
    [BS-V1 BOM v1.0.3.xlsx, bs.PrjPcb, p1_bt_sorry.SchDoc]
2019-04-05 Started PCB, roughing out placement
    [MCO.dwg, bs.PcbDoc, bs.PrjPcb]
2019-04-07 Added stackup to PCB
    [bs.PcbDoc, bs.PrjPcb]
2019-04-07 Apply rules to PCB
    [bs.PcbDoc, p1_bt_sorry.SchDoc]
2019-04-07 Placement in progress
    [bs.PcbDoc, bs.PrjPcb, p1_bt_sorry.SchDoc]
2019-04-08 Current DRC passing
    [bs.PcbDoc]
2019-04-08 Almost there
    [bs.PcbDoc, p1_bt_sorry.SchDoc]
2019-04-08 Initial placement done
    [bs.PcbDoc, p1_bt_sorry.SchDoc]
2019-04-08 Finished up placement
    [bs.PcbDoc, bs.PrjPcb, p1_bt_sorry.SchDoc]
2019-04-08 All import rules and DRC fixed
    [bs.PcbDoc, bs.PrjPcb, p1_bt_sorry.SchDoc]
2019-04-08 BS Schematic and Layout (v1.0.4): Placement Complete
    [BS-V1 BOM v1.0.4.xlsx, bs.PrjPcb, p1_bt_sorry.SchDoc]
2019-04-09 Planes in progress
    [bs.PcbDoc, bs.PrjPcb, p1_bt_sorry.SchDoc]
2019-04-09 Planes done, working on USB
    [bs.PcbDoc, bs.PrjPcb, p1_bt_sorry.SchDoc]
2019-04-09 Updating USB in progress
    [bs.PcbDoc, bs.PrjPcb, p1_bt_sorry.SchDoc]
2019-04-09 Updated filtering on USB
    [bs.PcbDoc, bs.PrjPcb, p1_bt_sorry.SchDoc]
2019-04-10 Routed and DRC passing
    [bs.PcbDoc, p1_bt_sorry.SchDoc]
2019-04-10 Prep for sch review'
    [bs.PcbDoc, bs.PrjPcb]
2019-04-10 Layout review completed
    [bs.PcbDoc, p1_bt_sorry.SchDoc]
2019-04-10 Silk done, ready for DFM
    [bs.PcbDoc, p1_bt_sorry.SchDoc]
2019-04-10 BS (v1.0.5): Layout Completed
    [BS-V1 BOM v1.0.5.xlsx, bs.PcbDoc, bs.PrjPcb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]
2019-04-10 Generated mfg files
    [BS-V1 BOM v1.0.5.xlsx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]
2019-04-11 Latest files
    [bs.GBL, bs.GBO, bs.GBP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]
2019-04-30 Remove keepout gerber to avoid China confusion
    [bs.GKO]
2019-07-07 Bring-up in progress for BS, button and 3.3V working
    [Bring-Up Testing Overview.xlsx, MCO Mockup v1.1.step, bs.PcbDoc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]
2019-09-04 Updated to new BOM format
    [BS-V1 BOM v1.0.5.xlsx, bs.PcbDoc, bs.PrjPcb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]
2020-02-16 Fixed U5 footprint
    [Battery Calculator.xlsx, Bring-Up Testing Overview.xlsx, bs.PcbDoc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]
2020-02-17 Added blinky, updated bring-up doc and added fixes doc
    [Bring-Up Testing Overview.xlsx]
2023-05-29 Clean up folder structure, add rev_b
    [BS-V1 BOM v1.0.3.xlsx, BS-V1 BOM v1.0.4.xlsx, BS-V1 BOM v1.0.5.xlsx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]
2023-05-29 Removed Microsoft documents
    [Battery Calculator.xlsx, Bring-Up Testing Overview.xlsx]

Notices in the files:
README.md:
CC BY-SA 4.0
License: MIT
